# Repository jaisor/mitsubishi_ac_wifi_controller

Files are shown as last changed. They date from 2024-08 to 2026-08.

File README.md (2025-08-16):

# Mitsubishi AC WiFi Controller with MQTT support

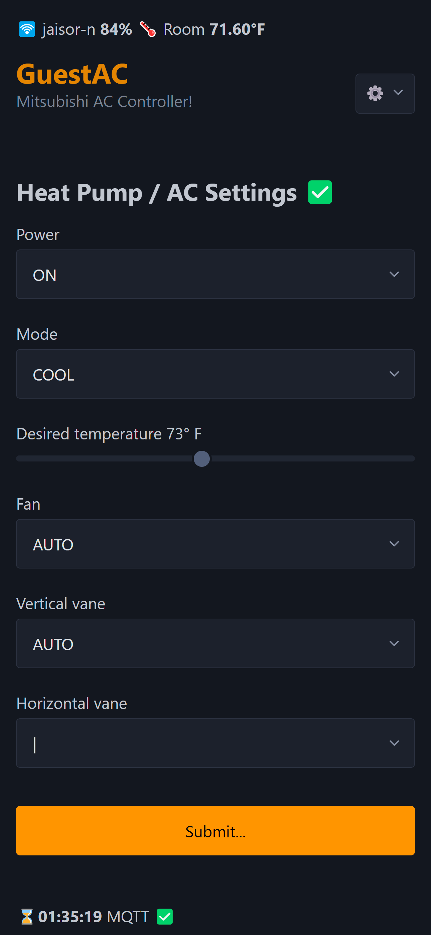
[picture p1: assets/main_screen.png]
main screen


Supported features:
* Web UI
* WiFi with both self-hosted or joining existing access points
* MQTT support
* OTA firmware update using ElegantOTA at `/update`
* 3D printed case for clean and seamless mounting

Based on:
* https://github.com/jaisor/stus-rf24-wifi-gw
* https://github.com/SwiCago/HeatPump

# Usage

## Initial boot / reset

On first boot the device creates a self-hosted WiFi access point (AP) with SSID starting with `ESP8266MHVAC` and WPA2 password `password123`
In self-hosted AP mode, the device gives itself `192.168.4.1` IP address.

The device can be connected to an existing AP using the `/wifi` option

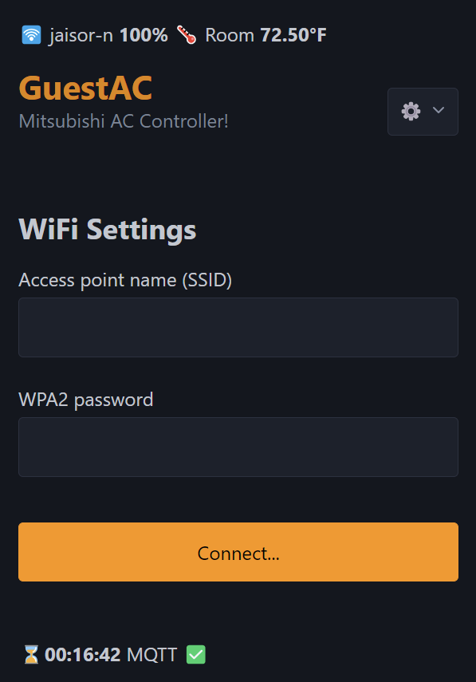
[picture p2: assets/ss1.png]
wifi screenshot


## Resetting / erasing configuration

The device will reset itself to default configuration and self-hosted AP if unable to complete its boot sequence within 2 seconds (smooth boot) 3 times in a row.
This can be forced by power-cycling the device several times. Powered up durations should be about 1 second (less than 2 second, but enough for the CPU to start). 

# Programming the ESP8266

Compile and upload the project using USB. After the resistors are removed (see below), future updates will have to be made using OTA. 
Access to OTA is at `/update` path at the device's IP. See Initial boot below on how to connect to the self-hosted AP.

# Assembly

The CN105 connected is underneath the unit cover. The cover can be a bit tricky and intimidating to remove. There are some hidden plastic latches that have to be forced and negotiated a bit.
Turn power to the unit and take any other appropriate precautions, ladder safety, etc. As with all DIY projects, proceed at your own risk. 

Resources showing how to remove the cover from Mitsubishi HVAC units:
* https://chrdavis.github.io/hacking-a-mitsubishi-heat-pump-Part-1/
* https://youtu.be/U0aPWvbfMRA?t=454

## Parts

* ESP8266 Chip ESP-12F style board - https://www.amazon.com/dp/B081PX9YFV/
* PCB dev board - https://www.amazon.com/dp/B0778G64QZ?ref=ppx_yo2ov_dt_b_fed_asin_title
* CN105 connector housing - https://www.digikey.com/en/products/detail/jst-sales-america-inc/PAP-05V-S/759977
* Connector pins - https://www.digikey.com/en/products/detail/jst-sales-america-inc/SPHD-002T-P0.5/608809
* Alternative pre-made CN105 cable - https://www.aliexpress.us/item/3256802718583041.html
* M3 x 4mm bolts for mounting the board in the case - https://www.amazon.com/dp/B08H2HCBQM/
* (Optional) 4 pin connectors so the unit can be disconnected without having to take the HVAC cover off again - https://www.amazon.com/gp/product/B01DUC1S14

## Removing the RX/TX resistors

The RX/TX resistors have to be removed on some variants of the ESP8266 board, like "Wemos D1 Mini" and other similar ones.
Easiest way is to heat them up with a soldering gun, or pry them off with tweezers. 
Keep in mind you will not be able to upload builds via USB anymore, so do this is a final step before connecting to the heat pump.
Future updates will have to happen over OTA

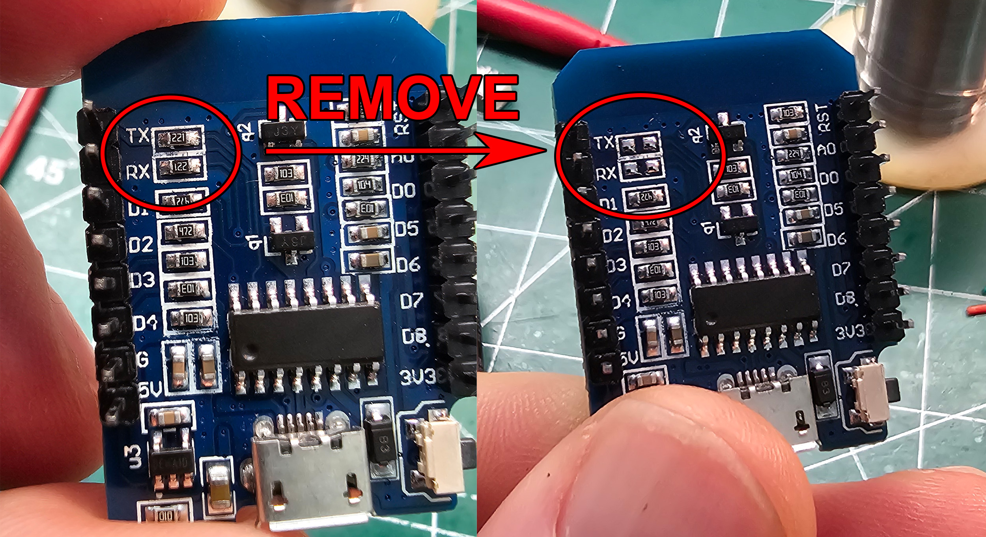
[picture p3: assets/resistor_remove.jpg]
resistor remove


## Wiring



Link to source - https://www.geekzone.co.nz/forums.asp?forumid=73&topicid=303958

```
| 12V | - not connected
| GND | - GND
| 5V  | - 5V
| TX  | - RXD0 / GPIO3
| RX  | - TXD0 / GPIO1
```

ESP8266 pinout

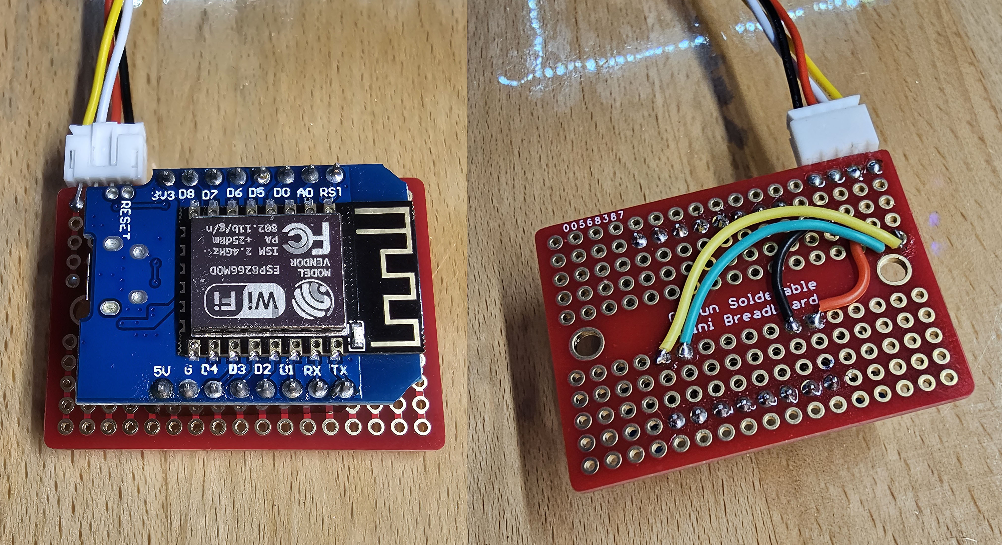
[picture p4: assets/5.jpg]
pcb


## Case

3D printable case is available
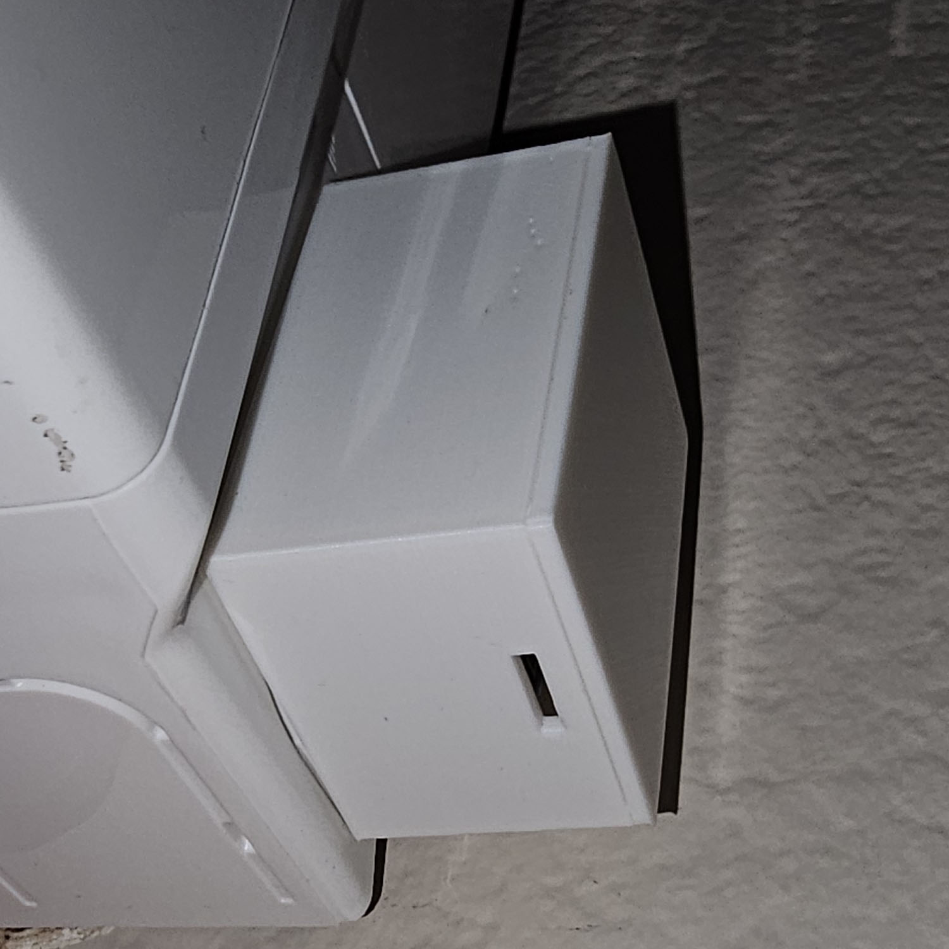
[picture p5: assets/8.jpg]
pcb back


* [case base](assets/HVACBoxBase.stl)
* [case lid](assets/HVACBoxLid.stl)

# Apache proxy setup

Example configuration for exposing a local network device via Apache proxy. Strong advised to use SSL/HTTPS and other appropriate authentication and authorization controls to prevent bad actors access. 

```
                <Location /ac>
                        AuthType Basic
                        Authname "Password Required"
                        AuthUserFile /etc/apache2/.htpasswd
                        Require valid-user
                </Location>

                RewriteRule ^/ac/roomname$ /ac/roomname/ [R]
                ProxyPass /ac/roomname/ http://192.168.x.y/ disablereuse=On
                ProxyPassReverse /ac/roomname/ http://192.168.x.y/
```

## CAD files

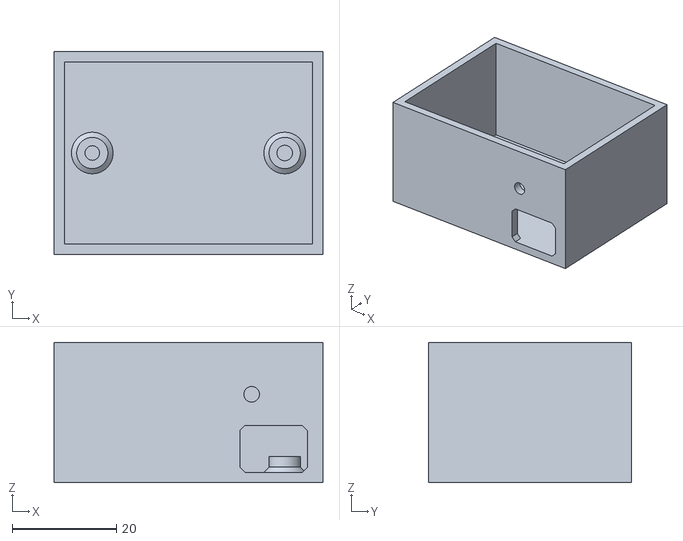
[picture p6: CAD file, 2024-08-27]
assets/HVACBoxBase.stl
51.7 x 39.0 x 27.0

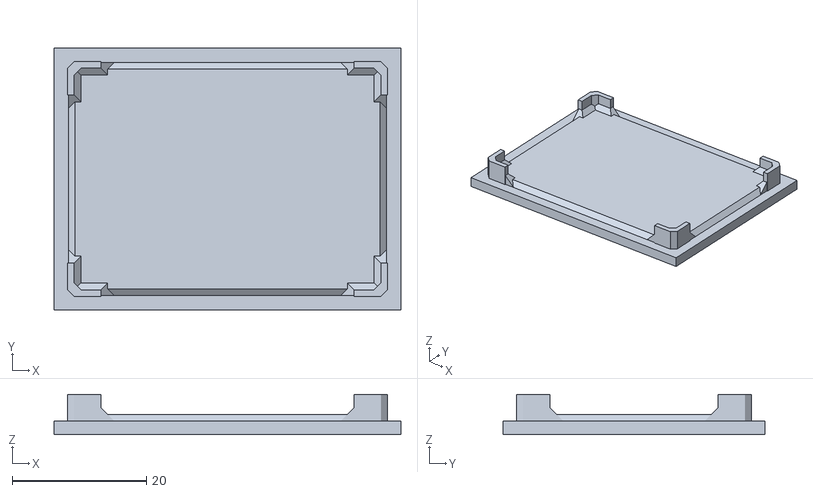
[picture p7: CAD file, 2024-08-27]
assets/HVACBoxLid.stl
51.7 x 39.0 x 6.00

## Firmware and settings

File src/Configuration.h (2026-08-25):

#pragma once

#include <Arduino.h>
#include <functional>
#include <ArduinoLog.h>
#include <StreamUtils.h>

//#define DEBUG_MOCK_HP
#define DISABLE_LOGGING
#ifndef DISABLE_LOGGING
  #define LOG_LEVEL LOG_LEVEL_VERBOSE
#endif

//#define WEB_LOGGING
#ifdef WEB_LOGGING
  #define WEB_LOG_LEVEL LOG_LEVEL_INFO
#endif

#define WIFI    // 2.4Ghz wifi access point

#define EEPROM_FACTORY_RESET 0       // Byte to be used for factory reset device fails to start or is rebooted within 1 sec 3 consequitive times
#define EEPROM_CONFIGURATION_START 1   // First EEPROM byte to be used for storing the configuration

#define FACTORY_RESET_CLEAR_TIMER_MS 2000   // Clear factory reset counter when elapsed, considered smooth boot

#if defined(ESP32)
  #define DEVICE_NAME "ESP32MHVAC"
#elif defined(ESP8266)
  #define DEVICE_NAME "ESP8266MHVAC"
#endif

#ifdef WIFI
  #define WIFI_SSID DEVICE_NAME
  #define WIFI_PASS "password123"

  // If unable to connect, it will create a soft accesspoint
  #define WIFI_FALLBACK_SSID DEVICE_NAME // device chip id will be suffixed
  #define WIFI_FALLBACK_PASS "password123"

  #define NTP_SERVER "pool.ntp.org"
  #define NTP_GMT_OFFSET_SEC -25200
  #define NTP_DAYLIGHT_OFFSET_SEC 0

  // Web server
  #define WEB_SERVER_PORT 80
#endif

// #define BATTERY_SENSOR  // ADC A0 using 0-3.3v voltage divider
#ifdef BATTERY_SENSOR
  #define BATTERY_VOLTS_DIVIDER 57.2 // 162.3 - 4.2v max; 57.2 - 14.8v max;
  #if defined(ESP32)
    #define BATTERY_SENSOR_ADC_PIN  A0
  #elif defined(ESP8266)
    #define BATTERY_SENSOR_ADC_PIN  A0
  #elif defined(SEEED_XIAO_M0)
    #define BATTERY_SENSOR_ADC_PIN  D1
  #else
    #define BATTERY_SENSOR_ADC_PIN  0
  #endif
#endif

// #define TEMP_SENSOR
#ifdef TEMP_SENSOR
  #define TEMP_UNIT_CELSIUS     0
  #define TEMP_UNIT_FAHRENHEIT  1
  //#define TEMP_SENSOR_DS18B20
  //#define TEMP_SENSOR_BME280
  #define TEMP_SENSOR_DHT
  #ifdef TEMP_SENSOR_DHT
    #define TEMP_SENSOR_DHT_TYPE   DHT22
  #endif
  #ifdef TEMP_SENSOR_BME280
    #define BME_SEALEVELPRESSURE_HPA (1013.25)
    #define BME_I2C_ID 0x76
  #endif
  #if defined(ESP32)
    #define TEMP_SENSOR_PIN 0
  #elif defined(ESP8266)
    #define TEMP_SENSOR_PIN D3
  #elif defined(SEEED_XIAO_M0)
    #define TEMP_SENSOR_PIN D4
  #endif
#endif

#define HVAC_CTRL
#ifdef HVAC_CTRL
  #define TEMP_UNIT_CELSIUS     0
  #define TEMP_UNIT_FAHRENHEIT  1
#endif

#define HOME_ASSISTANT  // MQTT discovery for the Home Assistant climate component
#ifdef HOME_ASSISTANT
  #define HA_DISCOVERY_PREFIX "homeassistant"
  #define HA_NODE_ID_LEN 64
  #define HA_TOPIC_LEN 224
  // The heat pump is native Celsius; Home Assistant converts for display.
  #define HA_MIN_TEMP 16
  #define HA_MAX_TEMP 31
  #define HA_TEMP_STEP 1
  // Floor between change driven state publishes, so a burst of heat pump
  // callbacks can't flood the broker.
  #define HA_STATE_MIN_INTERVAL_MS 1000
  // How often to sample the heat pump for externally made changes
  #define HA_CHANGE_POLL_MS 500
#endif

#define INTERNAL_LED_PIN LED_BUILTIN

struct configuration_t {

  #ifdef WIFI
    char wifiSsid[32];
    char wifiPassword[63];
    
    // ntp
    char ntpServer[128];
    long gmtOffset_sec;
    int daylightOffset_sec;

    // mqtt
    char mqttServer[128];
    uint16_t mqttPort;
    char mqttTopic[128];
  #endif

  char name[128];
  #ifdef BATTERY_SENSOR
    float battVoltsDivider;
  #endif
  #if defined(TEMP_SENSOR) || defined(HVAC_CTRL)
    uint8_t tempUnit;
  #endif

  uint8_t ledEnabled;

  char _loaded[7]; // used to check if EEPROM was correctly set
};

extern configuration_t configuration;
#ifdef WEB_LOGGING
  extern StringPrint logStream;
#endif

uint8_t EEPROM_initAndCheckFactoryReset();
void EEPROM_clearFactoryReset();

void EEPROM_saveConfig();
void EEPROM_loadConfig();
void EEPROM_wipe();

uint32_t CONFIG_getDeviceId();
unsigned long CONFIG_getUpTime();

void intLEDOn();
void intLEDOff();
void intLEDBlink(uint16_t ms);

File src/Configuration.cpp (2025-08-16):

#include <Arduino.h>
#include <EEPROM.h>
#include <version.h>
#include "Configuration.h"

configuration_t configuration;
#ifdef WEB_LOGGING
  StringPrint logStream;
#endif

uint8_t EEPROM_initAndCheckFactoryReset() {
  Log.noticeln("Configuration size: %i", sizeof(configuration_t));
  
  EEPROM.begin(sizeof(configuration_t) + EEPROM_FACTORY_RESET + 1);
  uint8_t resetCounter = EEPROM.read(EEPROM_FACTORY_RESET);

  Log.noticeln("Factory reset counter: %i", resetCounter);
  Log.noticeln("EEPROM length: %i", EEPROM.length());

  #if defined(ESP32)
  portMUX_TYPE mx = portMUX_INITIALIZER_UNLOCKED;
  taskENTER_CRITICAL(&mx);
  #endif

  // Bump reset counter
  EEPROM.write(EEPROM_FACTORY_RESET, resetCounter + 1);
  EEPROM.commit();

  #if defined(ESP32)
  taskEXIT_CRITICAL(&mx);
  #endif

  return resetCounter;
}

void EEPROM_clearFactoryReset() {
  #if defined(ESP32)
  portMUX_TYPE mx = portMUX_INITIALIZER_UNLOCKED;
  taskENTER_CRITICAL(&mx);
  #endif
  
  EEPROM.write(EEPROM_FACTORY_RESET, 0);
  EEPROM.commit();

  #if defined(ESP32)
  taskEXIT_CRITICAL(&mx);
  #endif
}

void EEPROM_saveConfig() {
  #if defined(ESP32)
  portMUX_TYPE mx = portMUX_INITIALIZER_UNLOCKED;
  taskENTER_CRITICAL(&mx);
  #endif
  
  Log.infoln("Saving configuration to EEPROM");
  EEPROM.put(EEPROM_CONFIGURATION_START, configuration);
  Log.verboseln("Committing EEPROM");
  EEPROM.commit();

  #if defined(ESP32)
  taskEXIT_CRITICAL(&mx);
  #endif
}

void EEPROM_loadConfig() {

  configuration = {};
  EEPROM.get(EEPROM_CONFIGURATION_START, configuration);

  Log.noticeln("Configuration loaded: %s", configuration._loaded);

  //strcpy(configuration.wifiSsid, "");
  //strcpy(configuration.wifiPassword, "");

  if (strcmp(configuration._loaded, "jaisor")) {
    // blank
    Log.infoln("Blank configuration, loading defaults");
    strcpy(configuration._loaded, "jaisor");
    strcpy(configuration.name, DEVICE_NAME);
    configuration.ledEnabled = true;
    #ifdef WIFI
      strcpy(configuration.ntpServer, NTP_SERVER);
      configuration.gmtOffset_sec = NTP_GMT_OFFSET_SEC;
      configuration.daylightOffset_sec = NTP_DAYLIGHT_OFFSET_SEC;
      strcpy(configuration.mqttServer, "");
      configuration.mqttPort = 1883;
      strcpy(configuration.mqttTopic, "");
    #endif

    #ifdef BATTERY_SENSOR
      configuration.battVoltsDivider = BATTERY_VOLTS_DIVIDER;
    #endif
    #ifdef TEMP_SENSOR
      configuration.tempUnit = TEMP_UNIT_FAHRENHEIT;
    #endif

    EEPROM_saveConfig();
  }

#ifdef WIFI
  String wifiStr = String(configuration.wifiSsid);
  for (auto i : wifiStr) {
    if (!isAscii(i)) {
      Log.verboseln("Bad SSID, loading default: %s", wifiStr.c_str());
      strcpy(configuration.wifiSsid, "");
      break;
    }
  }
#endif

  Log.noticeln("Device name: %s", configuration.name);
  Log.noticeln("Version: %s", VERSION);
}

void EEPROM_wipe() {
  Log.warningln("Wiping configuration with size %i!", EEPROM.length());
  for (uint16_t i = 0; i < EEPROM.length() ; i++) {
    EEPROM.write(i, 0);
  }
  EEPROM.commit();
}

uint32_t CONFIG_getDeviceId() {
    // Create AP using fallback and chip ID
  uint32_t chipId = 0;
  #ifdef ESP32
    for(int i=0; i<17; i=i+8) {
    chipId |= ((ESP.getEfuseMac() >> (40 - i)) & 0xff) << i;
    }
  #elif ESP8266
    chipId = ESP.getChipId();
  #endif

  return chipId;
}

static unsigned long tMillisUp = millis();
unsigned long CONFIG_getUpTime() {  
  return millis() - tMillisUp;
}

static bool isIntLEDOn = false;
void intLEDOn() {
  if (configuration.ledEnabled) {
    #if (defined(SEEED_XIAO_M0) || defined(ESP8266))
      digitalWrite(INTERNAL_LED_PIN, LOW);
    #else
      digitalWrite(INTERNAL_LED_PIN, HIGH);
    #endif
    isIntLEDOn = true;
  }
}

void intLEDOff() {
  #if (defined(SEEED_XIAO_M0) || defined(ESP8266))
    digitalWrite(INTERNAL_LED_PIN, HIGH);
  #else
    digitalWrite(INTERNAL_LED_PIN, LOW);
  #endif
  isIntLEDOn = false;
}

void intLEDBlink(uint16_t ms) {
  if (isIntLEDOn) { intLEDOff(); } else { intLEDOn(); }
  delay(ms);
  if (isIntLEDOn) { intLEDOff(); } else { intLEDOn(); }
}

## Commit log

2024-08-10 initial commit, still lots to clean up from the RF24 GW base
    [Configuration.h]
2024-08-10 Added the HeatPump lib
2024-08-10 cleaning up RF24 code and prep for heat pump impl
    [Configuration.h]
2024-08-19 Fixed ElegantOTA issue, and started on HeatPump integration
    [Device.cpp]
2024-08-20 8266 compatibility, more work on heat pump integration
2024-08-21 Successful pull of AC settings on website
    [Configuration.h]
2024-08-22 fixed ESP32 and more work on web form for HeatPump
    [Configuration.h]
2024-08-22 Fix for ESP32C3
2024-08-23 Before conversion to Pico html
    [Configuration.h]
2024-08-23 Pico html works
2024-08-24 minor tweaks
    [Configuration.h]
2024-08-24 work on updating ac settings
    [Configuration.h]
2024-08-24 update working, small issue with temperature unit conversion
    [Device.cpp]
2024-08-26 fixed fan ui bugs
    [Device.cpp]
2024-08-26 fixed vane and widevane, added led disable feature in device settings
    [Configuration.h]
2024-08-27 Readme work and assets
    [HVACBoxBase.stl, HVACBoxLid.stl]
2024-08-27 resistor remove
2024-08-30 added web log at /log and mqtt disconnect in an attempt to fix it dropping occasionally
    [Configuration.h]
2024-08-31 fixed the mqtt disconnect issue, added reboot url
    [Configuration.h]
2024-09-01 work on rest API
    [Configuration.h]
2024-10-13 prod build
    [Configuration.h]
2025-08-16 library update and esp32c3 compatibility
    [Configuration.h]
2025-08-30 github action and removed logging
    [Configuration.h]
2025-08-30 Disabled logging so UART works correctly
    [Configuration.h]
2026-08-25 feat: support for HomeAssistant climate component
    [Configuration.h]
